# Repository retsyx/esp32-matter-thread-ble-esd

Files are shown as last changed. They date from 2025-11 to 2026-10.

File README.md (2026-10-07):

# Matter Over Thread End Sleepy Device With BLE Commissioning

Implements a motion sensor with an ESP32 and a BMA400 IMU - be notified when the mailman delivers your mail by attaching an accelerometer to the mailbox lid. This code puts together all the bits that seem to be required for a Matter over Thread End Sleepy Device (ESD) with BLE commissioning.

## Power Consumption

This setup seems to average 650µA at 4V from the battery when idling. Detected motion spikes power consumption considerably. The ESP32-C6's idle power draw is very high and not practical for long lived, battery powered, Matter devices.

## Requirements

* An Espressif ESP32 device with a Thread and BLE radio (for example, the ESP32-C6). If using a battery, the device should ideally have a charging circuit to allow charging the LiPo that will power the device. [The SparkFun Qwiic Pocket Development Board](https://www.sparkfun.com/products/22925) has an onboard charger, and is easy to interface with a suitable accelerometer.
* Bosch BMA400 accelerometer. The [SparkFun BMA400 Qwicc board](https://www.sparkfun.com/products/21207) interfaces easily with the SparkFun Qwiic Pocket.
* LiPo Battery. If using the linked SparkFun board, use a battery with a JST PH 2.0mm connector. Ensure that the polarity of the battery leads match the polarity of the board connector. The SparkFun Qwicc Pocket's connector polarity is the opposite of most hobby LiPos sold. Battery connector pins can be easily pried out with a utility knife to reverse their position in the connector.

### Custom Board

Alternatively, an untested custom PCB design based on the XIAO ESP32-C6 and the BMA400 accelerometer is [available](hw/board).

The LiPo Battery JST PH 2.0mm connector polarity for this board matches the typically available LiPo polarity.

## Building

* Install [esp-idf](https://docs.espressif.com/projects/esp-idf/en/stable/esp32/index.html) and [esp-matter](https://docs.espressif.com/projects/esp-matter/en/latest/esp32/)
* Set the target.
    * For the Sparkfun board use esp32-c6.
    * For the custom board, enable **Example Configuration → Use the XIAO ESP32-C6 carrier board** in (`idf.py menuconfig` (`CONFIG_BOARD_XIAO_ESP32C6=y`).
* Build the project, and flash to device

## Commissioning

With your favorite Matter commissioner (HomeKit, etc.) add the accessory.

This project uses development commissioning credentials, so the QR code is always the one below.

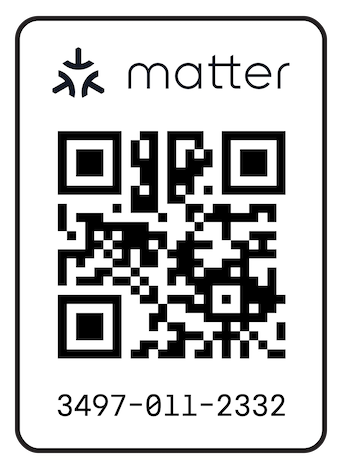
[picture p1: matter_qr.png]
matter provisioning QR code


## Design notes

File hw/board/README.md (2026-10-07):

# XIAO ESP32-C6 / BMA400 Board

**This board has not been manufactured or tested.**

It is a simple board designed in KiCad.

## Manufacturing

It is a standard 2-layer, 1.6mm FR4 board. Dimensions are 40mm x 32mm.

Manufacturing files are available [here](mfr/).

An example BOM is available [here](mfr/bom.csv).

## Building the Firmware

From the repository root, set the ESP-IDF target to `esp32c6`, then enable **Example Configuration → Use the XIAO ESP32-C6 carrier board** in `idf.py menuconfig` (`CONFIG_BOARD_XIAO_ESP32C6=y`).

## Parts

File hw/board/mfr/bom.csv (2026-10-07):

References | Quantity | Value or description | Footprint | Manufacturer | Manufacturer part number | Tolerance | Voltage rating | Dielectric | Power rating | Datasheet URL | Assembly | Notes
U1 | 1 | XIAO ESP32-C6 | Board:XIAO_ESP32C6_SMD | Seeed Studio | 113991254 |  |  |  |  | https://files.seeedstudio.com/wiki/SeeedStudio-XIAO-ESP32C6/XIAO_ESP32_C6_v1.0_SCH_260114.pdf | SMD reflow
U2 | 1 | BMA400 | Board:LGA-12_2x2mm_P0.5mm | Bosch Sensortec | BMA400 |  |  |  |  | https://www.bosch-sensortec.com/media/boschsensortec/downloads/datasheets/bst-bma400-ds000.pdf | SMD reflow
J1 | 1 | JST PH 2.0mm horizontal 2-pin battery connector | Board:JST_PH_S2B-PH-K_1x02_P2.00mm_Horizontal | JST | S2B-PH-K-S(LF)(SN) |  |  |  |  | https://www.jst-mfg.com/product/pdf/eng/ePH.pdf | Through-hole
R1,R2 | 2 | 10k | Board:R_0603_1608Metric | Panasonic Industry | ERJ-3EKF1002V | 1% |  |  | 0.1W | https://industrial.panasonic.com/cdbs/www-data/pdf/RDA0000/AOA0000C304.pdf | SMD 0603 | 10kohm, 1%, 0.1W, 0603 (1608 metric)
R3,R4 | 2 | 200k | Board:R_0603_1608Metric | Panasonic Industry | ERJ-3EKF2003V | 1% |  |  | 0.1W | https://industrial.panasonic.com/cdbs/www-data/pdf/RDA0000/AOA0000C304.pdf | SMD 0603 | 200kohm, 1%, 0.1W, 0603 (1608 metric)
C1,C2,C4 | 3 | 100nF | Board:C_0603_1608Metric | KEMET | C0603C104K5RACTU | 10% | 50V | X7R |  | https://yageogroup.com/content/datasheet/asset/file/KEM_C1002_X7R_SMD | SMD 0603 | 100nF, 50V, X7R, 10%, 0603 (1608 metric)
C3 | 1 | 1uF | Board:C_0603_1608Metric | KEMET | C0603C105K4RACTU | 10% | 16V | X7R |  | https://yageogroup.com/content/datasheet/asset/file/KEM_C1002_X7R_SMD | SMD 0603 | 1uF, 16V, X7R, 10%, 0603 (1608 metric)

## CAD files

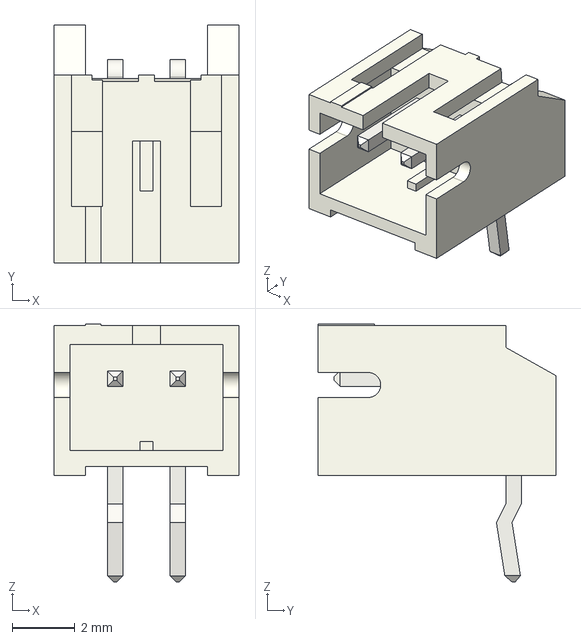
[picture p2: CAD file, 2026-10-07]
hw/board/3dmodels/JST_PH_S2B-PH-K_1x02_P2.00mm_Horizontal.step
5.90 x 7.60 x 8.25 mm

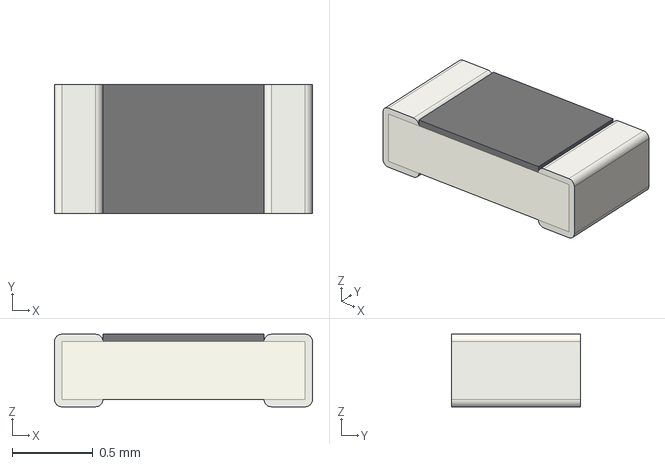
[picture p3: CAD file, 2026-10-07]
hw/board/3dmodels/R_0603_1608Metric.step
1.60 x 0.8 x 0.45 mm

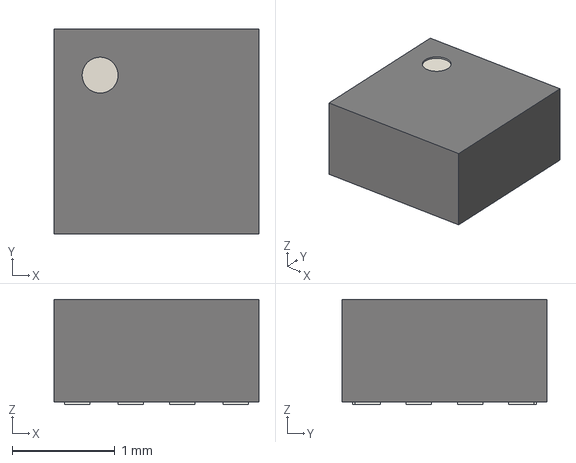
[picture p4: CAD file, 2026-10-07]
hw/board/3dmodels/LGA-12_2x2mm_P0.5mm.step
2.00 x 2.00 x 1.02 mm

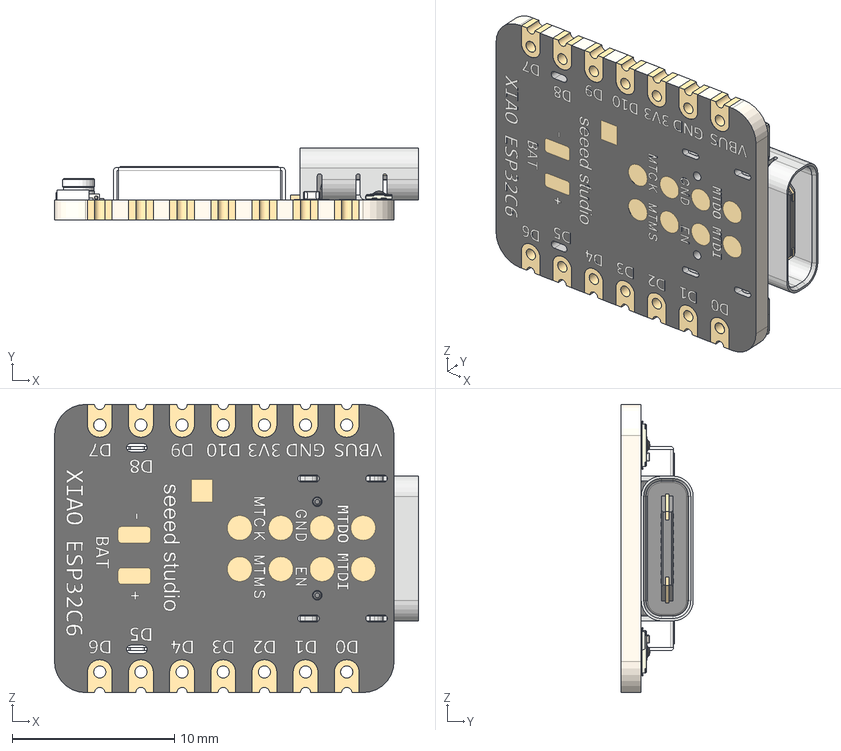
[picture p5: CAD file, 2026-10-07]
hw/board/3dmodels/XIAO_ESP32C6.step
22.5 x 4.47 x 17.8 mm
SKTAAAE010 x 2
KH5220-A36 (Ceramic Antenna) v2
Shield
U.FL Connector v1
BOSS-EXTRUDE14_8_
BOSS-EXTRUDE7_4_
BOSS-EXTRUDE7_3_
BOSS-EXTRUDE14_4_
BOSS-EXTRUDE14_2_
BOSS-EXTRUDE14_11_
BOSS-EXTRUDE7_7_
BOSS-EXTRUDE14_9_
BOSS-EXTRUDE14_3_
BOSS-EXTRUDE14_7_
MIRROR2
BOSS-EXTRUDE14_5_
BOSS-EXTRUDE14_12_
BOSS-EXTRUDE7_8_
BOSS-EXTRUDE7_1_
BOSS-EXTRUDE14_10_
BOSS-EXTRUDE7_9_
BOSS-EXTRUDE14_6_
BOSS-EXTRUDE14_1_
BOSS-EXTRUDE7_6_
BOSS-EXTRUDE7_2_
CUT-EXTRUDE5
BOSS-EXTRUDE7_5_
Composant32
C0402
C0402_1
C01005_1 x 2
C01005

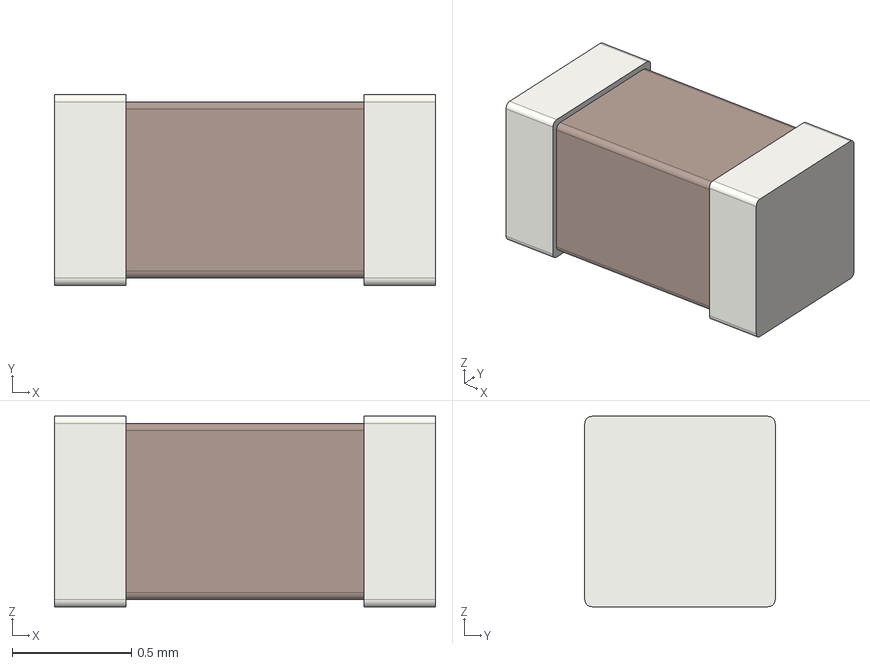
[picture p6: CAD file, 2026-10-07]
hw/board/3dmodels/C_0603_1608Metric.step
1.60 x 0.8 x 0.8 mm

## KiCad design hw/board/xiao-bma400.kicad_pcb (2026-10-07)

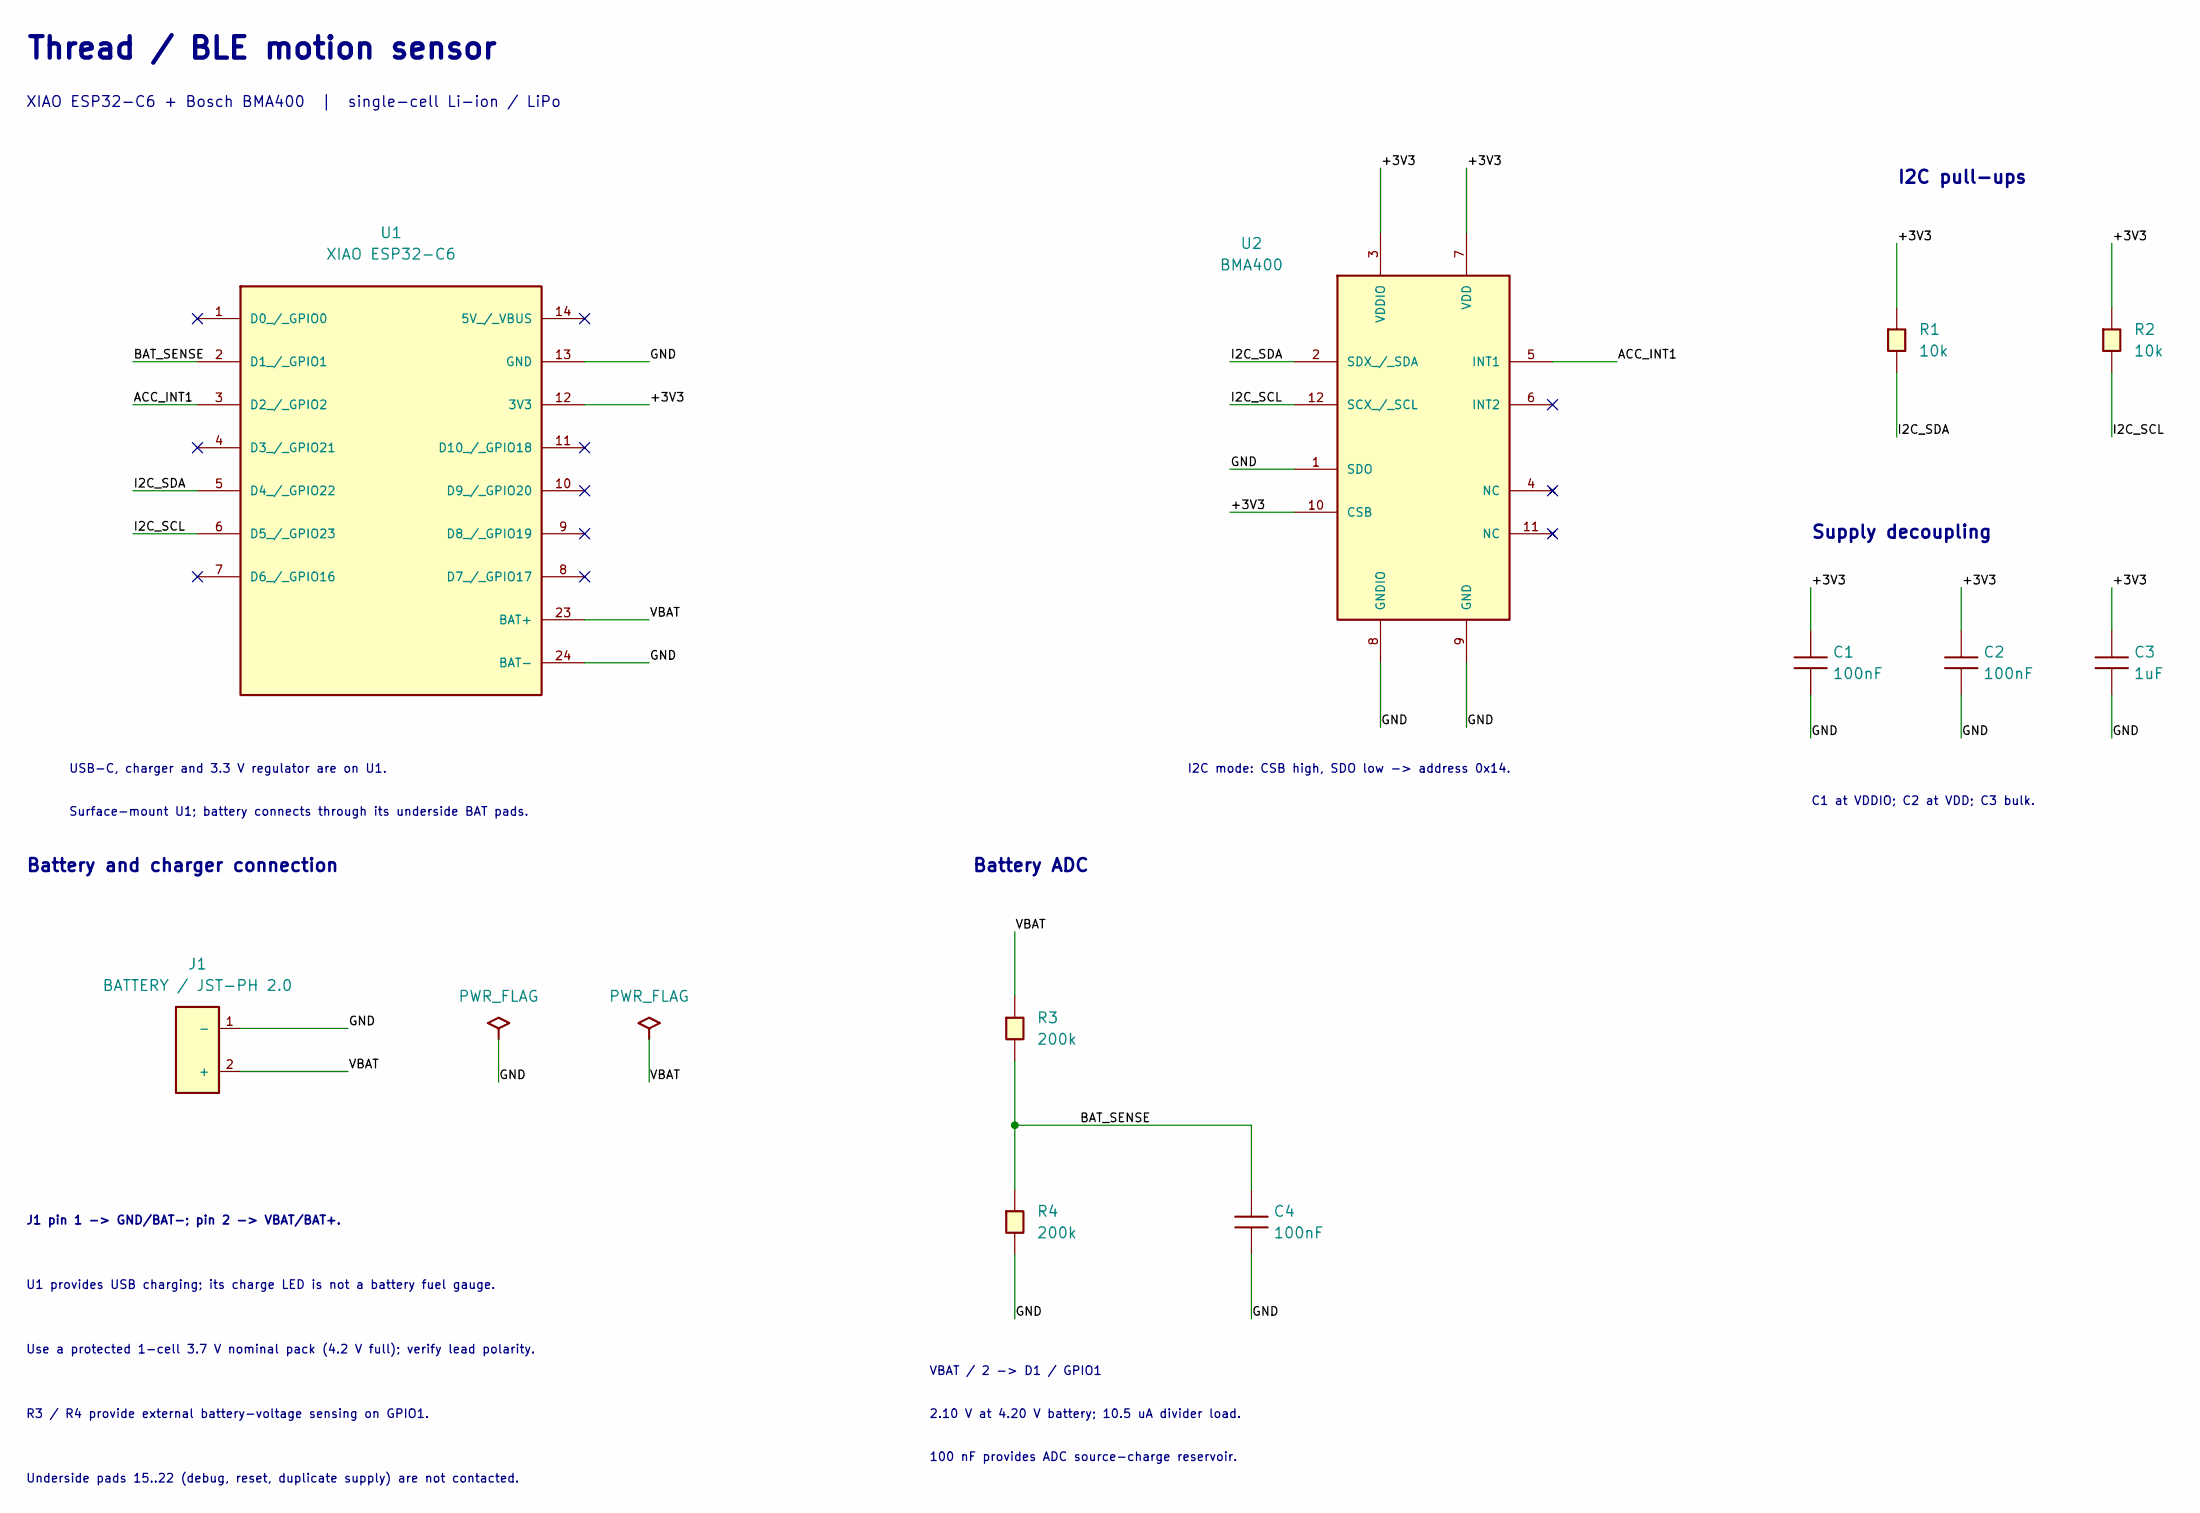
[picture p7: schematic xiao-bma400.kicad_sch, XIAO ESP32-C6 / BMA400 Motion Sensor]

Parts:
C1, C2, C4: 100nF; C_0603_1608Metric; Tolerance 10%; Voltage 50V; MPN C0603C104K5RACTU
C3: 1uF; C_0603_1608Metric; Tolerance 10%; Voltage 16V; MPN C0603C105K4RACTU
J1: BATTERY / JST-PH 2.0; JST_PH_S2B-PH-K_1x02_P2.00mm_Horizontal; MPN S2B-PH-K-S(LF)(SN)
R1, R2: 10k; R_0603_1608Metric; Tolerance 1%; MPN ERJ-3EKF1002V
R3, R4: 200k; R_0603_1608Metric; Tolerance 1%; MPN ERJ-3EKF2003V
U1: XIAO ESP32-C6; XIAO_ESP32C6_SMD; MPN 113991254
U2: BMA400; LGA-12_2x2mm_P0.5mm; MPN BMA400

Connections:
/+3V3: C1.1, C2.1, C3.1, R1.1, R2.1, U1.12 (3V3), U2.3 (VDDIO), U2.7 (VDD), U2.10 (CSB)
/ACC_INT1: U1.3 (D2_/_GPIO2), U2.5 (INT1)
/BAT_SENSE: C4.1, R3.2, R4.1, U1.2 (D1_/_GPIO1)
/GND: C1.2, C2.2, C3.2, C4.2, J1.1 (-), R4.2, U1.13 (GND), U1.24 (BAT-), U2.1 (SDO), U2.8 (GNDIO), U2.9 (GND)
/I2C_SCL: R2.2, U1.6 (D5_/_GPIO23), U2.12 (SCX_/_SCL)
/I2C_SDA: R1.2, U1.5 (D4_/_GPIO22), U2.2 (SDX_/_SDA)
/VBAT: J1.2 (+), R3.1, U1.23 (BAT+)

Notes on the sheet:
Battery ADC
C1 at VDDIO; C2 at VDD; C3 bulk.
Battery and charger connection
I2C mode: CSB high, SDO low -> address 0x14.
Use a protected 1-cell 3.7 V nominal pack (4.2 V full); verify lead polarity.
USB-C, charger and 3.3 V regulator are on U1.
U1 provides USB charging; its charge LED is not a battery fuel gauge.
Surface-mount U1; battery connects through its underside BAT pads.
XIAO ESP32-C6 + Bosch BMA400 | single-cell Li-ion / LiPo
Underside pads 15..22 (debug, reset, duplicate supply) are not contacted.
2.10 V at 4.20 V battery; 10.5 uA divider load.
VBAT / 2 -> D1 / GPIO1
100 nF provides ADC source-charge reservoir.
Thread / BLE motion sensor
Supply decoupling
R3 / R4 provide external battery-voltage sensing on GPIO1.
I2C pull-ups
J1 pin 1 -> GND/BAT-; pin 2 -> VBAT/BAT+.

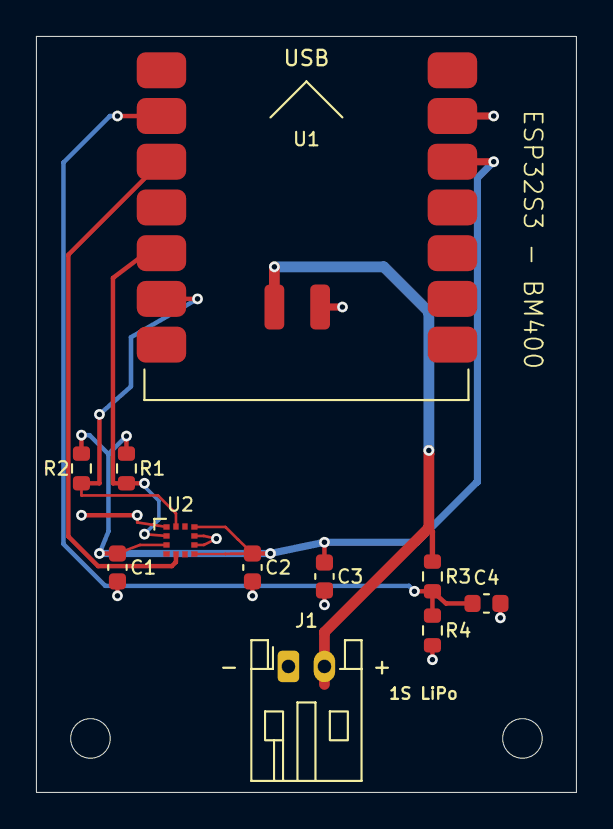
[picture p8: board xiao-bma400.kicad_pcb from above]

Board: 2 copper layers, 30.0 x 42.0 mm, 13 parts (0 on the bottom side), 7 nets.

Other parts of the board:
H1, H2: MountingHole_2.2mm_M2

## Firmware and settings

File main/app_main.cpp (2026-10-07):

/*
   This example code is in the Public Domain (or CC0 licensed, at your option.)

   Unless required by applicable law or agreed to in writing, this
   software is distributed on an "AS IS" BASIS, WITHOUT WARRANTIES OR
   CONDITIONS OF ANY KIND, either express or implied.
*/

#include <app/server/CommissioningWindowManager.h>
#include <app/server/Server.h>
#include <clusters/occupancy_sensing/integration.h>
#include <setup_payload/OnboardingCodesUtil.h>
#include <bsp/esp-bsp.h>
#include <esp_adc/adc_cali.h>
#include <esp_adc/adc_cali_scheme.h>
#include <esp_adc/adc_oneshot.h>
#include <esp_err.h>
#include <esp_log.h>
#include <esp_matter.h>
#include <esp_matter_ota.h>
#include <esp_openthread_netif_glue.h>
#include <esp_pm.h>
#include <esp_timer.h>
#include <esp_vfs_eventfd.h>
#include <nvs_flash.h>
#include <driver/gpio.h>
#include <driver/i2c.h>
#include <app_openthread_config.h>
#include <app_reset.h>
#include <common_macros.h>
#include <sdkconfig.h>

#include <button_gpio.h>

#include "sparkfun_bma400.h"

using namespace esp_matter;
using namespace esp_matter::attribute;
using namespace esp_matter::endpoint;
using namespace chip::app::Clusters;

#ifdef CONFIG_BOARD_XIAO_ESP32C6
#define ACC_INTERRUPT_PIN GPIO_NUM_2  // XIAO D2; supports light-sleep wakeup.
#define I2C_MASTER_SDA_IO GPIO_NUM_22  // XIAO D4
#define I2C_MASTER_SCL_IO GPIO_NUM_23  // XIAO D5
#else
#define ACC_INTERRUPT_PIN GPIO_NUM_5
#define I2C_MASTER_SDA_IO GPIO_NUM_6
#define I2C_MASTER_SCL_IO GPIO_NUM_7
#endif

#define I2C_MASTER_FREQ_HZ 100000   /*!< I2C master clock frequency */

typedef struct {
    uint16_t sensor_endpoint_id;
    uint16_t battery_endpoint_id;
} endpoint_data_t;

static const char *TAG = "app_main";

static endpoint_data_t endpoint_data;
static esp_timer_handle_t battery_timer_handle;

static esp_err_t init_i2c(i2c_port_t port = I2C_NUM_0)
{
    ESP_LOGI(TAG, "Initializing I2C on port %d", port);

    i2c_config_t i2c_config = {
        .mode = I2C_MODE_MASTER,
        .sda_io_num = I2C_MASTER_SDA_IO,
        .scl_io_num = I2C_MASTER_SCL_IO,
        .sda_pullup_en = GPIO_PULLUP_ENABLE,
        .scl_pullup_en = GPIO_PULLUP_ENABLE,
        .master = {
            .clk_speed = I2C_MASTER_FREQ_HZ,
        },
    };

    esp_err_t err = i2c_param_config(port, &i2c_config);
    if (err != ESP_OK) {
        ESP_LOGE(TAG, "Failed to configure I2C driver, err: %d", err);
        return err;
    }

    err = i2c_driver_install(port, I2C_MODE_MASTER, 0, 0, 0);
    if (err != ESP_OK) {
        ESP_LOGE(TAG, "Failed to install driver, err: %d", err);
        return err;
    }

    return ESP_OK;
}

static esp_err_t deinit_i2c(i2c_port_t port = I2C_NUM_0) {
    ESP_LOGI(TAG, "Denitializing I2C on port %d", port);
    return i2c_driver_delete(port);
}

// Both boards connect a 1:1 battery divider to GPIO1 (XIAO D1).
#define BATTERY_ADC_PIN ADC_CHANNEL_1

static adc_oneshot_unit_handle_t adc1_handle;

static esp_err_t init_battery_adc()
{
    adc_oneshot_unit_init_cfg_t init_config1 = {
        .unit_id = ADC_UNIT_1,
        .ulp_mode = ADC_ULP_MODE_DISABLE,
    };
    ESP_ERROR_CHECK(adc_oneshot_new_unit(&init_config1, &adc1_handle));

    adc_oneshot_chan_cfg_t config = {
        .atten = ADC_ATTEN_DB_12,
        .bitwidth = ADC_BITWIDTH_DEFAULT,
    };
    ESP_ERROR_CHECK(adc_oneshot_config_channel(adc1_handle, BATTERY_ADC_PIN, &config));

    ESP_LOGI(TAG, "Battery ADC inited");

    return ESP_OK;
}

static esp_err_t deinit_battery_adc()
{
    ESP_ERROR_CHECK(adc_oneshot_del_unit(adc1_handle));

    ESP_LOGI(TAG, "Battery ADC deinited");

    return ESP_OK;
}

static int get_battery_percentage()
{
    int dout = 0;
    int mv = 0;
    // init/deinit ADC for every read because there is a bug where ADC reads return bogus data
    // after light sleep otherwise.
    init_battery_adc();

    const adc_cali_curve_fitting_config_t calibration_config = {
        .unit_id = ADC_UNIT_1,
        .chan = BATTERY_ADC_PIN,
        .atten = ADC_ATTEN_DB_12,
        .bitwidth = ADC_BITWIDTH_DEFAULT,
    };
    adc_cali_handle_t calibration_handle = nullptr;
    esp_err_t err = adc_cali_create_scheme_curve_fitting(&calibration_config, &calibration_handle);
    if (err != ESP_OK) {
        deinit_battery_adc();
        ESP_LOGE(TAG, "Failed to calibrate battery ADC: %s", esp_err_to_name(err));
        return -1;
    }

    err = adc_oneshot_read(adc1_handle, BATTERY_ADC_PIN, &dout);
    if (err == ESP_OK) {
        err = adc_cali_raw_to_voltage(calibration_handle, dout, &mv);
    }
    ESP_ERROR_CHECK(adc_cali_delete_scheme_curve_fitting(calibration_handle));
    deinit_battery_adc();
    if (err != ESP_OK) {
        ESP_LOGE(TAG, "Failed to read calibrated battery ADC: %s", esp_err_to_name(err));
        return -1;
    }

    ESP_LOGI(TAG, "Battery ADC raw %d, calibrated %d mV (battery level %d mV)", dout, mv, 2*mv);

    // Max voltage is defined as 4.2V = 4200mV
    // Min voltage is defined as 3.5V = 3500mV
    // We are measuring voltage on the midpoint of a voltage divider, so divide by 2.
    const int min_mv = 3500 / 2;
    const int max_mv = 4200 / 2;

    if (mv < min_mv) {
        mv = min_mv;
    } else if (mv > max_mv) {
        mv = max_mv;
    }

    int p = 100 * (mv - min_mv) / (max_mv - min_mv);

    ESP_LOGI(TAG, "Battery percentage %d%%", p);

    return p;
}

static void battery_cb(void *arg)
{
    endpoint_data_t e = *(endpoint_data_t *)arg;

    // Read battery level
    int p = get_battery_percentage();
    bool is_low = p < 20;
    auto call = [e, p, is_low]() {
        // Power Source uses the attribute store, unlike the Occupancy cluster server.
        // Matter represents battery percentage as a nullable uint8 in half-percent units.
        esp_matter_attr_val_t val = esp_matter_nullable_uint8(nullable<uint8_t>(static_cast<uint8_t>(p * 2)));
        esp_err_t err = attribute::update(e.battery_endpoint_id, PowerSource::Id,
                                         PowerSource::Attributes::BatPercentRemaining::Id, &val);
        if (err != ESP_OK) {
            ESP_LOGE(TAG, "Battery percentage update failed on endpoint %u: %s",
                     e.battery_endpoint_id, esp_err_to_name(err));
            return;
        }

        val = esp_matter_bool(is_low);
        err = attribute::update(e.battery_endpoint_id, PowerSource::Id,
                                PowerSource::Attributes::BatReplacementNeeded::Id, &val);
        if (err != ESP_OK) {
            ESP_LOGE(TAG, "Battery replacement update failed on endpoint %u: %s",
                     e.battery_endpoint_id, esp_err_to_name(err));
            return;
        }
        ESP_LOGI(TAG, "Battery endpoint %u updated: %d%% replacement_needed=%d",
                 e.battery_endpoint_id, p, is_low);
    };

    // schedule the attribute update so that we can report it from matter thread
    if (p >= 0) {
        CHIP_ERROR err = chip::DeviceLayer::SystemLayer().ScheduleLambda([call] { call(); });
        if (err != CHIP_NO_ERROR) {
            ESP_LOGE(TAG, "Failed to schedule battery update: %" CHIP_ERROR_FORMAT, err.Format());
        }
    } else {
        ESP_LOGW(TAG, "Battery sample unavailable; keeping the previous reported value");
    }

    // Restart the timer
    uint64_t period_us = 24ULL * 3600ULL * 1000000ULL;
    esp_err_t err = esp_timer_start_once(battery_timer_handle, period_us);
    if (err != ESP_OK) {
        ESP_LOGE(TAG, "Failed to start timer, err: %d", err);
    }
}

#define CHECK(A) do { int x; if ((x = (A))) ESP_LOGI(TAG, "Error %d "#A, x); } while (false)

static esp_err_t init_acc()
{
    init_i2c();

    BMA400 accelerometer;

    while (accelerometer.beginI2C() != BMA400_OK) {
        ESP_LOGE(TAG, "BMA400 not connected, check wiring and I2C address!");
        vTaskDelay(pdMS_TO_TICKS(1000));
    }

    ESP_LOGI(TAG, "BMA400 initialized");

#if 0
    accelerometer.getSensorData();
    ESP_LOGI(TAG, "acc %.2f %.2f %.2f",
        accelerometer.data.accelX,
        accelerometer.data.accelY,
        accelerometer.data.accelZ);
#endif

    // Configure wakeup interrupt
    bma400_wakeup_conf wakeupConfig = {
        .wakeup_ref_update = BMA400_UPDATE_ONE_TIME,
        .sample_count = BMA400_SAMPLE_COUNT_8,
        .wakeup_axes_en = BMA400_AXIS_XYZ_EN,
        .int_wkup_threshold = 4,
        .int_wkup_ref_x = 255,
        .int_wkup_ref_y = 255,
        .int_wkup_ref_z = 255,
        .int_chan = BMA400_INT_CHANNEL_1
    };
    CHECK(accelerometer.setWakeupInterrupt(&wakeupConfig));

    // Configure the INT1 pin to push/pull mode, active high
    CHECK(accelerometer.setInterruptPinMode(BMA400_INT_CHANNEL_1, BMA400_INT_PUSH_PULL_ACTIVE_1));

    // Enable auto wakeup interrupt condition
    CHECK(accelerometer.enableInterrupt(BMA400_AUTO_WAKEUP_EN, true));

    // Set up automatic transition to low power mode
    bma400_auto_lp_conf autoLPConfig = {
        .auto_low_power_trigger = BMA400_AUTO_LP_TIME_RESET_EN,
        .auto_lp_timeout_threshold = 400  // 1 second timeout
    };
    CHECK(accelerometer.setAutoLowPower(&autoLPConfig));

    // Configure generic interrupt to reset auto low power timer
    bma400_gen_int_conf config = {
        .gen_int_thres = 5,
        .gen_int_dur = 1,
        .axes_sel = BMA400_AXIS_XYZ_EN,
        .data_src = BMA400_DATA_SRC_ACCEL_FILT_2,
        .criterion_sel = BMA400_ACTIVITY_INT,
        .evaluate_axes = BMA400_ANY_AXES_INT,
        .ref_update = BMA400_UPDATE_EVERY_TIME,
        .hysteresis = BMA400_HYST_48_MG,
        .int_thres_ref_x = 0,
        .int_thres_ref_y = 0,
        .int_thres_ref_z = 512,
        .int_chan = BMA400_UNMAP_INT_PIN
    };
    CHECK(accelerometer.setGeneric2Interrupt(&config));

    // Enable generic 2 interrupt condition
    CHECK(accelerometer.enableInterrupt(BMA400_GEN2_INT_EN, true));

    CHECK(accelerometer.setMode(BMA400_MODE_LOW_POWER));

    deinit_i2c();

    return ESP_OK;
}

static void acc_cb(void *arg, void *data)
{
    endpoint_data_t e = *(endpoint_data_t *)data;

    // We got an interrupt from the accelerometer, generate an update
    ESP_LOGI(TAG, "Motion detected!");

    auto call = [e](bool value) {
        auto *occupancy = OccupancySensing::FindClusterOnEndpoint(e.sensor_endpoint_id);
        if (occupancy == nullptr) {
            ESP_LOGE(TAG, "Occupancy cluster missing on endpoint %u", e.sensor_endpoint_id);
            return;
        }

        // The cluster server owns Occupancy; generic attribute writes are unsupported.
        occupancy->SetOccupancy(value);
        ESP_LOGI(TAG, "Occupancy endpoint %u requested: %d actual: %d",
                 e.sensor_endpoint_id, value, occupancy->IsOccupied());
    };

    // schedule the attribute update so that we can report it from matter thread
    chip::DeviceLayer::SystemLayer().ScheduleLambda([call] { call(true); });

    vTaskDelay(pdMS_TO_TICKS(5000));

    chip::DeviceLayer::SystemLayer().ScheduleLambda([call] { call(false); });

    init_acc();
}

static esp_err_t init_battery_timer(endpoint_data_t * endpoint_data)
{
    esp_timer_create_args_t args = {
        .callback = battery_cb,
        .arg = endpoint_data,
        .dispatch_method = ESP_TIMER_TASK,
        .name = "battery",
        .skip_unhandled_events = true,
    };
    return esp_timer_create(&args, &battery_timer_handle);
}

static esp_err_t init_gpio_button(endpoint_data_t * endpoint_data)
{
    button_handle_t btn_handle;
    // Setup the GPIO 'button' to wake us up when the accelerometer pulls the pin high
    button_config_t btn_conf = {0};

    button_gpio_config_t gpio_conf {
        .gpio_num = ACC_INTERRUPT_PIN,
        .active_level = 1,
        .enable_power_save = true,
        .disable_pull = true,
    };

    esp_err_t err = iot_button_new_gpio_device(&btn_conf, &gpio_conf, &btn_handle);
    VerifyOrReturnError(err == ESP_OK, err);

    err = iot_button_register_cb(btn_handle, BUTTON_PRESS_DOWN, NULL, acc_cb, endpoint_data);
    VerifyOrReturnError(err == ESP_OK, err);

    ESP_LOGI(TAG, "Created GPIO button");
    return err;
}

static void open_commissioning_window_if_necessary()
{
    VerifyOrReturn(chip::Server::GetInstance().GetFabricTable().FabricCount() == 0);

    chip::CommissioningWindowManager & commissionMgr = chip::Server::GetInstance().GetCommissioningWindowManager();
    VerifyOrReturn(commissionMgr.IsCommissioningWindowOpen() == false);

    // After removing last fabric, this example does not remove the Wi-Fi credentials
    // and still has IP connectivity so, only advertising on DNS-SD.
    CHIP_ERROR err = commissionMgr.OpenBasicCommissioningWindow(chip::System::Clock::Seconds16(300),
                                    chip::CommissioningWindowAdvertisement::kAllSupported);
    if (err != CHIP_NO_ERROR)
    {
        ESP_LOGE(TAG, "Failed to open commissioning window, err:%" CHIP_ERROR_FORMAT, err.Format());
    }
}

static void enable_sleep()
{
    esp_pm_config_t pm_config = {
        .max_freq_mhz = CONFIG_ESP_DEFAULT_CPU_FREQ_MHZ,
        .min_freq_mhz = 40,
        .light_sleep_enable = true
    };
    ESP_ERROR_CHECK(esp_pm_configure(&pm_config));
}

static void app_event_cb(const ChipDeviceEvent *event, intptr_t arg)
{
    switch (event->Type) {
    case chip::DeviceLayer::DeviceEventType::kCommissioningWindowOpened:
        ESP_LOGI(TAG, "Commissioning window opened");
        PrintOnboardingCodes(chip::RendezvousInformationFlags(chip::RendezvousInformationFlag::kOnNetwork));
        break;

    case chip::DeviceLayer::DeviceEventType::kCommissioningWindowClosed:
        ESP_LOGI(TAG, "Commissioning window closed");
        break;

    case chip::DeviceLayer::DeviceEventType::kCommissioningComplete:
        ESP_LOGI(TAG, "Commissioning complete");
        enable_sleep();
        break;

    case chip::DeviceLayer::DeviceEventType::kFailSafeTimerExpired:
        ESP_LOGI(TAG, "Commissioning failed, fail safe timer expired");
        break;

    case chip::DeviceLayer::DeviceEventType::kThreadConnectivityChange:
        ESP_LOGI(TAG, "Thread connectivity changed %d", event->ThreadConnectivityChange.Result);
        break;

    case chip::DeviceLayer::DeviceEventType::kFabricRemoved:
        ESP_LOGI(TAG, "Fabric removed successfully");
        open_commissioning_window_if_necessary();
        break;

    case chip::DeviceLayer::DeviceEventType::kBLEDeinitialized:
        ESP_LOGI(TAG, "BLE deinitialized and memory reclaimed");
        break;

    case chip::DeviceLayer::DeviceEventType::kSecureSessionEstablished:
        ESP_LOGI(TAG, "Established secure session");
        break;

    default:
        ESP_LOGI(TAG, "Unhandled event %d", event->Type);
        break;
    }
}

// This callback is invoked when clients interact with the Identify Cluster.
// In the callback implementation, an endpoint can identify itself. (e.g., by flashing an LED or light).
static esp_err_t app_identification_cb(identification::callback_type_t type, uint16_t endpoint_id, uint8_t effect_id,
                                       uint8_t effect_variant, void *priv_data)
{
    ESP_LOGI(TAG, "Identification callback: type: %u, effect: %u, variant: %u", type, effect_id, effect_variant);
    return ESP_OK;
}

// This callback is called for every attribute update. The callback implementation shall
// handle the desired attributes and return an appropriate error code. If the attribute
// is not of your interest, please do not return an error code and strictly return ESP_OK.
static esp_err_t app_attribute_update_cb(attribute::callback_type_t type, uint16_t endpoint_id, uint32_t cluster_id,
                                         uint32_t attribute_id, esp_matter_attr_val_t *val, void *priv_data)
{
    // Since this is just a sensor and we don't expect any writes on our temperature sensor,
    // so, return success.
    return ESP_OK;
}

extern "C" void app_main()
{
    esp_err_t err;

#ifdef CONFIG_BOARD_XIAO_ESP32C6
    // Power the XIAO RF switch and select its onboard antenna for BLE/Thread.
    ESP_ERROR_CHECK(gpio_set_level(GPIO_NUM_3, 0));
    ESP_ERROR_CHECK(gpio_set_level(GPIO_NUM_14, 0));
    ESP_ERROR_CHECK(gpio_set_direction(GPIO_NUM_3, GPIO_MODE_OUTPUT));
    ESP_ERROR_CHECK(gpio_set_direction(GPIO_NUM_14, GPIO_MODE_OUTPUT));
    // Keep the antenna controls stable when light sleep powers down peripherals.
    ESP_ERROR_CHECK(gpio_hold_en(GPIO_NUM_3));
    ESP_ERROR_CHECK(gpio_hold_en(GPIO_NUM_14));
#endif

    /* Initialize the ESP NVS layer */
    nvs_flash_init();

    /* Create a Matter node and add the mandatory Root Node device type on endpoint 0 */
    node::config_t root_config;
    node_t *root = node::create(&root_config, app_attribute_update_cb, app_identification_cb);
    ABORT_APP_ON_FAILURE(root != nullptr, ESP_LOGE(TAG, "Failed to create Matter root node"));

    // Add the occupancy sensor
    occupancy_sensor::config_t occupancy_sensor_config;
    occupancy_sensor_config.occupancy_sensing.feature_flags = cluster::occupancy_sensing::feature::passive_infrared::get_id();
    occupancy_sensor_config.occupancy_sensing.occupancy_sensor_type =
        chip::to_underlying(OccupancySensing::OccupancySensorTypeEnum::kPir);
    occupancy_sensor_config.occupancy_sensing.occupancy_sensor_type_bitmap =
        chip::to_underlying(OccupancySensing::OccupancySensorTypeBitmap::kPir);

    endpoint_t * occupancy_sensor_ep = occupancy_sensor::create(root, &occupancy_sensor_config, ENDPOINT_FLAG_NONE, NULL);
    ABORT_APP_ON_FAILURE(occupancy_sensor_ep != nullptr, ESP_LOGE(TAG, "Failed to create occupancy_sensor endpoint"));
    endpoint_data.sensor_endpoint_id = endpoint::get_id(occupancy_sensor_ep);

    // Add the battery reporting device
    power_source::config_t power_source_config;
    power_source_config.power_source.feature_flags = cluster::power_source::feature::battery::get_id();
    endpoint_t *power_source_ep = power_source::create(root, &power_source_config, ENDPOINT_FLAG_NONE, NULL);
    ABORT_APP_ON_FAILURE(power_source_ep != nullptr, ESP_LOGE(TAG, "Failed to create power_source endpoint"));
    esp_matter::cluster_t *cluster = esp_matter::cluster::get(power_source_ep, chip::app::Clusters::PowerSource::Id);
    attribute_t *battery_percentage = cluster::power_source::attribute::create_bat_percent_remaining(
        cluster, nullable<uint8_t>(), 0, 200);
    ABORT_APP_ON_FAILURE(battery_percentage != nullptr, ESP_LOGE(TAG, "Failed to create battery percentage attribute"));

    endpoint_data.battery_endpoint_id = endpoint::get_id(power_source_ep);

    err = init_gpio_button(&endpoint_data);
    ABORT_APP_ON_FAILURE(err == ESP_OK, ESP_LOGE(TAG, "Failed to initialize GPIO button"));

    // init accelerometer
    err = init_acc();
    ABORT_APP_ON_FAILURE(err == ESP_OK, ESP_LOGE(TAG, "Failed to initialize accelerometer"));

    err = init_battery_timer(&endpoint_data);
    ABORT_APP_ON_FAILURE(err == ESP_OK, ESP_LOGE(TAG, "Failed to initialize battery timer"));

#if CHIP_DEVICE_CONFIG_ENABLE_THREAD
    /* Set OpenThread platform config */
    esp_openthread_platform_config_t config = {
        .radio_config = ESP_OPENTHREAD_DEFAULT_RADIO_CONFIG(),
        .host_config = ESP_OPENTHREAD_DEFAULT_HOST_CONFIG(),
        .port_config = ESP_OPENTHREAD_DEFAULT_PORT_CONFIG(),
    };
    set_openthread_platform_config(&config);
#endif

    /* Matter start */
    err = esp_matter::start(app_event_cb);
    ABORT_APP_ON_FAILURE(err == ESP_OK, ESP_LOGE(TAG, "Failed to start Matter, err:%d", err));

    battery_cb(&endpoint_data);

    if (chip::Server::GetInstance().GetFabricTable().FabricCount() != 0) {
        enable_sleep();
    }
}

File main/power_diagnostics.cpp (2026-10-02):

#include "sdkconfig.h"

#if CONFIG_APP_POWER_DIAGNOSTICS

#include "power_diagnostics.h"

#include <cstdio>
#include <esp_attr.h>
#include <esp_log.h>
#include <esp_pm.h>
#include <esp_timer.h>
#include <freertos/FreeRTOS.h>
#include <freertos/task.h>
#include <platform/CHIPDeviceConfig.h>

#if CONFIG_BT_ENABLED
#include <esp_bt.h>
#endif

#if CHIP_DEVICE_CONFIG_ENABLE_THREAD
#include <esp_ieee802154.h>
#include <esp_openthread.h>
#include <esp_openthread_lock.h>
#include <openthread/link.h>
#include <openthread/thread.h>
#endif

static const char *TAG = "power_diag";
static gpio_num_t s_motion_pin;
static portMUX_TYPE s_sleep_stats_lock = portMUX_INITIALIZER_UNLOCKED;
static uint64_t s_sleep_call_us;
static uint64_t s_longest_sleep_call_us;
static uint32_t s_sleep_calls;
static int64_t s_monitor_start_us;

static esp_err_t IRAM_ATTR record_sleep_duration(int64_t duration_us, void *)
{
    // Called from the idle task's critical section. Never log or block here.
    if (duration_us > 0) {
        portENTER_CRITICAL_ISR(&s_sleep_stats_lock);
        s_sleep_call_us += duration_us;
        ++s_sleep_calls;
        if (static_cast<uint64_t>(duration_us) > s_longest_sleep_call_us) {
            s_longest_sleep_call_us = duration_us;
        }
        portEXIT_CRITICAL_ISR(&s_sleep_stats_lock);
    }
    return ESP_OK;
}

static void stop_sleep_measurement()
{
    esp_pm_sleep_cbs_register_config_t callbacks = {};
    callbacks.exit_cb = record_sleep_duration;
    esp_pm_light_sleep_unregister_cbs(&callbacks);
}

static void dump_sleep_duration()
{
    const int64_t elapsed_us = esp_timer_get_time() - s_monitor_start_us;
    portENTER_CRITICAL(&s_sleep_stats_lock);
    const uint64_t sleep_call_us = s_sleep_call_us;
    const uint64_t longest_us = s_longest_sleep_call_us;
    const uint32_t calls = s_sleep_calls;
    portEXIT_CRITICAL(&s_sleep_stats_lock);
    const uint64_t permille = elapsed_us > 0 ? sleep_call_us * 1000 / elapsed_us : 0;
    // IDF measures the entire sleep call, including entry/exit and rejected attempts.
    ESP_LOGI(TAG, "Sleep call duration: %llu/%lld us (%llu.%llu%%), calls=%lu longest_us=%llu",
             static_cast<unsigned long long>(sleep_call_us), static_cast<long long>(elapsed_us),
             static_cast<unsigned long long>(permille / 10),
             static_cast<unsigned long long>(permille % 10),
             static_cast<unsigned long>(calls), static_cast<unsigned long long>(longest_us));
}

#if CHIP_DEVICE_CONFIG_ENABLE_THREAD
static const char *radio_state_name(esp_ieee802154_state_t state)
{
    switch (state) {
    case ESP_IEEE802154_RADIO_DISABLE: return "disabled";
    case ESP_IEEE802154_RADIO_IDLE: return "idle";
    case ESP_IEEE802154_RADIO_SLEEP: return "sleep";
    case ESP_IEEE802154_RADIO_RECEIVE: return "receive";
    case ESP_IEEE802154_RADIO_TRANSMIT: return "transmit";
    default: return "unknown";
    }
}

static void dump_thread_state()
{
    if (!esp_openthread_lock_acquire(pdMS_TO_TICKS(100))) {
        ESP_LOGW(TAG, "Could not acquire OpenThread lock for snapshot");
        return;
    }
    otInstance *instance = esp_openthread_get_instance();
    if (instance == nullptr) {
        esp_openthread_lock_release();
        ESP_LOGW(TAG, "OpenThread instance unavailable");
        return;
    }
    const otDeviceRole role = otThreadGetDeviceRole(instance);
    const otLinkModeConfig mode = otThreadGetLinkMode(instance);
    const uint32_t poll_ms = otLinkGetPollPeriod(instance);
    const esp_ieee802154_state_t radio = esp_ieee802154_get_state();
    esp_openthread_lock_release();

    // Print outside the OpenThread lock so serial output cannot stall the stack.
    ESP_LOGI(TAG, "Thread role=%s rx_on_idle=%d full_device=%d poll_ms=%lu",
             otThreadDeviceRoleToString(role), mode.mRxOnWhenIdle, mode.mDeviceType,
             static_cast<unsigned long>(poll_ms));
    ESP_LOGI(TAG, "802.15.4 radio=%s", radio_state_name(radio));
}
#endif

static void diagnostic_task(void *)
{
    esp_pm_lock_handle_t console_lock = nullptr;
    if (esp_pm_lock_create(ESP_PM_NO_LIGHT_SLEEP, 0, "power_diag", &console_lock) != ESP_OK) {
        ESP_LOGE(TAG, "Failed to create diagnostic console lock");
        stop_sleep_measurement();
        vTaskDelete(nullptr);
        return;
    }
    for (unsigned sample = 1; sample <= 3; ++sample) {
        // This task blocks between samples; it does not poll during idle.
        vTaskDelay(pdMS_TO_TICKS(60000));
        // Light sleep disconnects native USB. Allow the host to reconnect for output.
        esp_pm_lock_acquire(console_lock);
        vTaskDelay(pdMS_TO_TICKS(2000));
        ESP_LOGI(TAG, "Power snapshot %u/3, uptime=%lld us", sample, esp_timer_get_time());

        esp_pm_config_t config = {};
        if (esp_pm_get_configuration(&config) == ESP_OK) {
            ESP_LOGI(TAG, "PM light_sleep=%d min_mhz=%d max_mhz=%d motion_gpio_level=%d",
                     config.light_sleep_enable, config.min_freq_mhz, config.max_freq_mhz,
                     gpio_get_level(s_motion_pin));
        }
#if CHIP_DEVICE_CONFIG_ENABLE_THREAD
        dump_thread_state();
#endif
#if CONFIG_BT_ENABLED
        ESP_LOGI(TAG, "BLE controller enabled=%d",
                 esp_bt_controller_get_status() == ESP_BT_CONTROLLER_STATUS_ENABLED);
#endif
        esp_pm_dump_locks(stdout);
        dump_sleep_duration();
        esp_timer_dump(stdout);
        fflush(stdout);
        vTaskDelay(pdMS_TO_TICKS(1000));
        esp_pm_lock_release(console_lock);
    }
    ESP_LOGI(TAG, "Power diagnostics complete; stopping diagnostic task");
    stop_sleep_measurement();
    esp_pm_lock_delete(console_lock);
    vTaskDelete(nullptr);
}

void start_power_diagnostics(gpio_num_t motion_pin)
{
    s_motion_pin = motion_pin;
    s_monitor_start_us = esp_timer_get_time();
    esp_pm_sleep_cbs_register_config_t callbacks = {};
    callbacks.exit_cb = record_sleep_duration;
    if (esp_pm_light_sleep_register_cbs(&callbacks) != ESP_OK) {
        ESP_LOGE(TAG, "Failed to register sleep duration callback");
        return;
    }
    if (xTaskCreate(diagnostic_task, "power_diag", 4096, nullptr, 1, nullptr) != pdPASS) {
        stop_sleep_measurement();
        ESP_LOGE(TAG, "Failed to create power diagnostic task");
    }
}

#endif // CONFIG_APP_POWER_DIAGNOSTICS

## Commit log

2026-10-02 Fixup battery measurement and reporting
    [app_main.cpp, power_diagnostics.cpp]
2026-10-07 Add XIAO ESP32-C6 based HW board
    [C_0603_1608Metric.step, JST_PH_S2B-PH-K_1x02_P2.00mm_Horizontal.step, LGA-12_2x2mm_P0.5mm.step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]

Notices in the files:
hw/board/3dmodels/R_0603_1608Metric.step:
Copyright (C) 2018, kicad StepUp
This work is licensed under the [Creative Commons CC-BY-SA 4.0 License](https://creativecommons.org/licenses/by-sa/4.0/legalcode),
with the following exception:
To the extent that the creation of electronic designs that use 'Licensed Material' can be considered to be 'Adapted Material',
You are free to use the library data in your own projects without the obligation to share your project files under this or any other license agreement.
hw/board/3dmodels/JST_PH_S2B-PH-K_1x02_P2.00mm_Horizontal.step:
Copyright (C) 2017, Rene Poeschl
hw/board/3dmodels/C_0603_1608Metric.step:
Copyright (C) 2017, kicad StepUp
